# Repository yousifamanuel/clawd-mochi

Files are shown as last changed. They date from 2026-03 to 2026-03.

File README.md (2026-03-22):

<!-- LOGO -->
<p align="center">
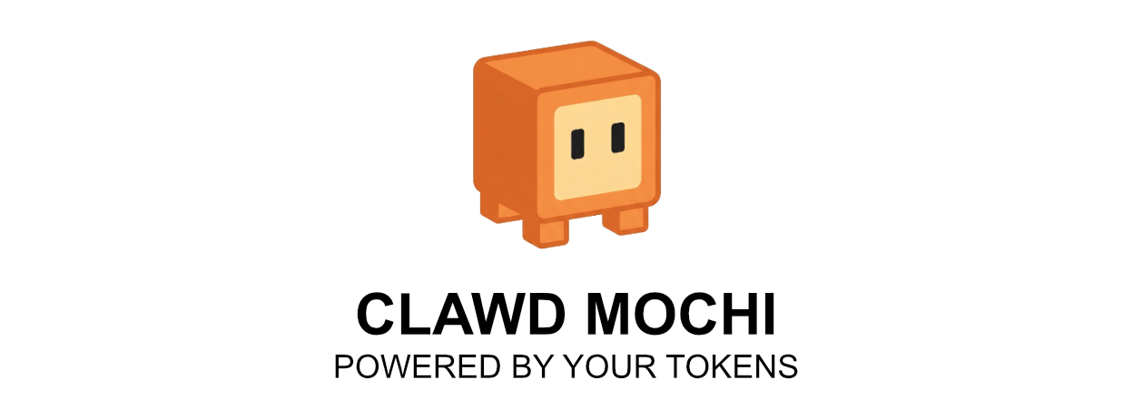
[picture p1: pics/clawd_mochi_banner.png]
Clawd Mochi Logo
  
</p>

# Clawd Mochi 🦀🤖

A physical desk companion inspired by **Clawd** — the pixel-crab mascot of Claude Code by Anthropic. An ESP32-C3 drives a 1.54" color TFT display and hosts a mobile web controller — no app, no internet, no cloud required.

**Cost: ~$6–8 · Build time: ~1 hour · Skill level: Beginner**

📦 3D printable case on MakerWorld: [https://makerworld.com/en/models/2559505-clawd-mochi-physical-claude-code-mascot#profileId-2820000](https://makerworld.com/en/models/2559505-clawd-mochi-physical-claude-code-mascot#profileId-2820000)

---

> ⚠️ This is an independent fan project. It is not affiliated with, sponsored by, or endorsed by Anthropic. "Claude" and "Clawd" are trademarks of Anthropic.

---

<p align="center">
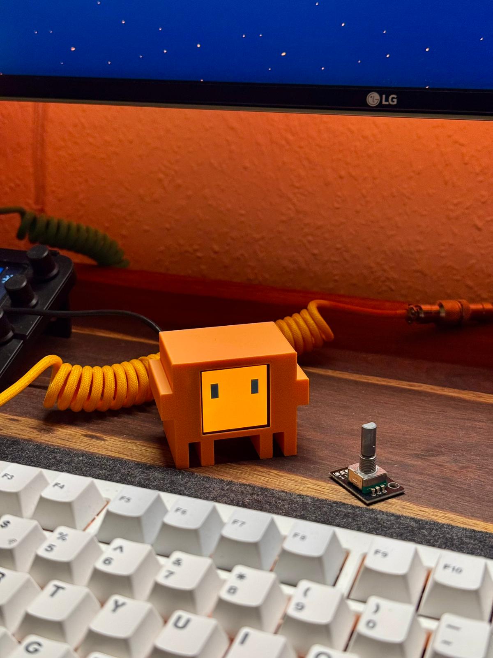
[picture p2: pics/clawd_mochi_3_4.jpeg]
Assembled Clawd Mochi on a desk
  
  &nbsp;
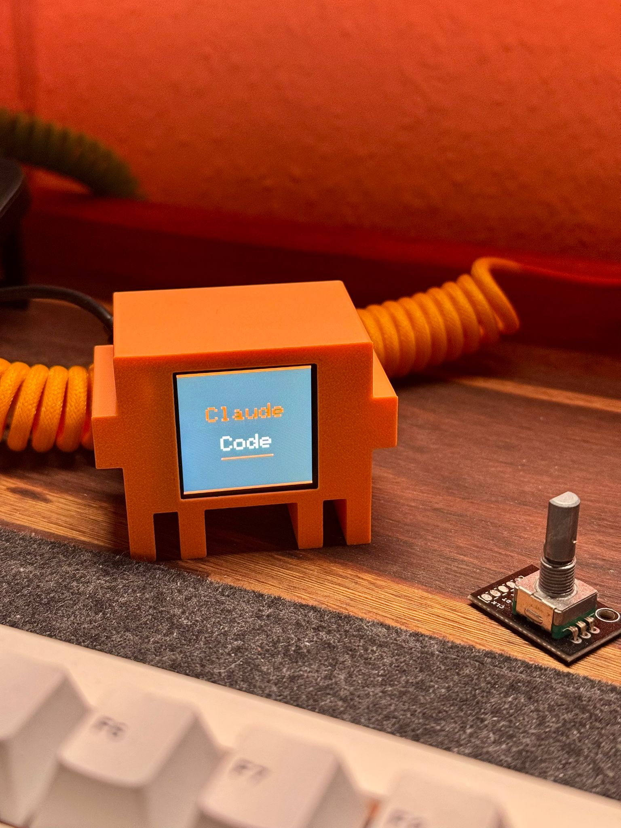
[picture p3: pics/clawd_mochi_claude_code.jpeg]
Claude Code view
  
</p>

## What it does

Clawd Mochi sits on your desk and shows animated expressions on a small color display. You control it from any phone or browser by connecting to its built-in WiFi hotspot:

- **Normal eyes** — pixel-art square eyes with wiggle and blink animations
- **Squish eyes** — `> <` happy squint with open/close animation
- **Claude Code** — displays "Claude Code" with an interactive terminal
- **Canvas** — draw anything on the display from your phone in real time

---

## Parts list

| Part | Spec | ~Price |
| --- | --- | --- |
| ESP32-C3 Super Mini | microcontroller with WiFi | ~$2.50 |
| ST7789 1.54" TFT | 240×240 SPI color display | ~$3.00 |
| 8 short wires | 8–10 cm Dupont / jumper wires | ~$0.50 |
| 2× M2×6mm screws | to mount display bezel | ~$0.10 |
| Double-sided tape | to secure components inside case | ~$0.10 |
| USB-C cable | for power | — |
| 3D printed case | PLA or PETG, ~30g | ~$0.50 |

**Total: ~$7–8**

---

## Wiring

> ⚠️ Connect VCC to **3.3V only** — never 5V. Use GPIO 8 and 10 for SPI (hardware SPI, fast). Do not use GPIO 6/7 for SPI.

| Display pin | ESP32-C3 GPIO  | Wire color (suggested) |
| --- | --- | --- |
| VCC | 3V3 | Red |
| GND | GND | Black |
| SDA | GPIO 10 (MOSI) | Orange |
| SCL | GPIO 8 (SCK) | Green |
| RES | GPIO 2 | Purple |
| DC | GPIO 1 | Blue |
| CS | GPIO 4 | White |
| BL | GPIO 3 | Yellow |

---

## Software setup

### Step 1 — Install Arduino IDE

Download [Arduino IDE 2.x](https://www.arduino.cc/en/software) and install it.

### Step 2 — Add ESP32 board support

1. Open Arduino IDE → **File → Preferences**
2. In "Additional boards manager URLs" paste:
   ```
   https://raw.githubusercontent.com/espressif/arduino-esp32/gh-pages/package_esp32_index.json
   ```
3. Go to **Tools → Board → Boards Manager**, search `esp32`, install **"esp32 by Espressif Systems"**

### Step 3 — Install libraries

Go to **Tools → Library Manager** and install both:

- `Adafruit GFX Library`
- `Adafruit ST7735 and ST7789 Library`

### Step 4 — Configure board settings

Go to **Tools** and set:

| Setting | Value |
| --- | --- |
| Board | ESP32C3 Dev Module |
| USB CDC On Boot | **Enabled** ← important |
| CPU Frequency | 160 MHz |
| Upload Speed | 921600 |

### Step 5 — Upload the sketch

1. Clone or download this repo
2. Open `clawd_mochi/clawd_mochi.ino` in Arduino IDE
3. Connect the ESP32 via USB-C
4. Select the correct port under **Tools → Port**
5. Click **Upload** (→ arrow button)
6. Wait for "Hard resetting via RTS pin..." — this means success

---

## How to use it

### Connect and open the controller

1. Power the ESP32 via USB-C (any USB charger or power bank)
2. Wait ~3 seconds for the boot animation to finish
3. On your phone or computer, go to **WiFi settings**
4. Connect to the network: **`ClaWD-Mochi`** · password: **`clawd1234`**
5. Open a browser and go to **`http://192.168.4.1`**

You should see the web controller:

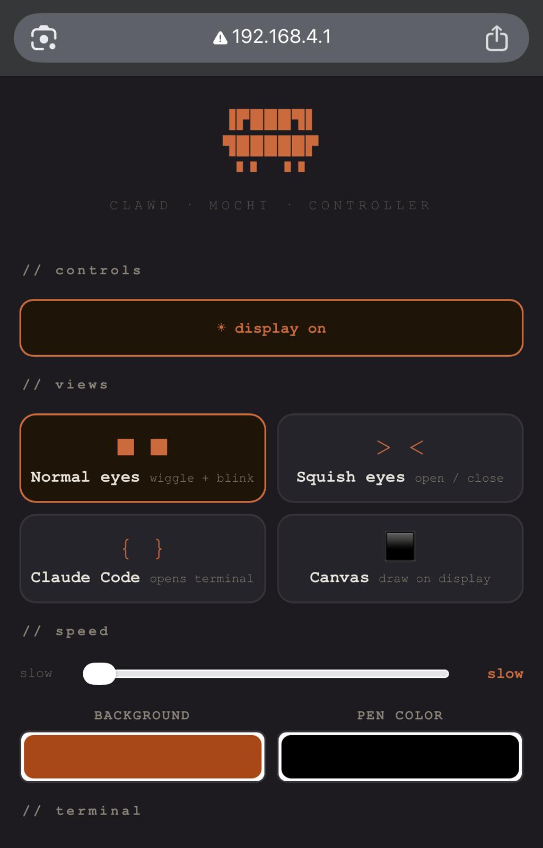
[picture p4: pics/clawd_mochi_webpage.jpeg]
Webpage view


### Controller features

| Button / control | What it does |
| --- | --- |
| Normal eyes | Plays wiggle + blink animation |
| Squish eyes | Plays open/close animation |
| Claude Code | Shows code display, opens terminal |
| Canvas | Enter drawing mode — draw on display from phone |
| Speed slider | Controls animation speed (slow / normal / fast) |
| Background color | Changes background color of all views |
| Pen color | Sets drawing color for canvas |
| Display on/off | Toggles the backlight |
| ✓ done (in canvas) | Exits canvas mode |

---

## 3D case

The case has two parts:

| File | Description |
| --- | --- |
| [`./models/clawd_mochi_body.stl`](./models/clawd_mochi_body.stl) | Main crab body with display window cutout |
| [`./models/clawd_mochi_back.stl`](./models/clawd_mochi_back.stl) | Back plate with USB-C access slot |

### Print settings

| Setting | Value |
| --- | --- |
| Material | PLA or PETG |
| Layer height | 0.15–0.20 mm |
| Infill | 15% gyroid |
| Supports | Yes — for display window overhang |
| Orientation  | Face-down, flat back on build plate |

Suggested colors: orange PLA for body, matte black for back plate.

You can also download the models from MakerWorld: [https://makerworld.com/en/models/2559505-clawd-mochi-physical-claude-code-mascot#profileId-2820000](https://makerworld.com/en/models/2559505-clawd-mochi-physical-claude-code-mascot#profileId-2820000)

---

## Assembly tips

1. Print both parts and test-fit the display before gluing anything
2. Thread the 8 wires through the back plate slot before soldering
3. Use double-sided tape to fix the ESP32 against the inside of the back plate
4. Secure the display with 2× M2×6mm screws through the bezel holes
5. Route the USB-C cable through the back plate slot and snap the back on

---

## Customisation

### Eye size and position

Edit these constants near the top of `clawd_mochi.ino`:

```cpp
#define EYE_W   30    // eye width in pixels
#define EYE_H   60    // eye height in pixels
#define EYE_GAP 120   // gap between eyes
#define EYE_OX  0     // horizontal offset
#define EYE_OY  40    // vertical offset upward
```

### Logo animation duration

```cpp
// In animLogoReveal() — how long logo holds after animation
delay(1500);       // milliseconds — change this number

// Speed of the reveal drawing stroke by stroke
delay(speedMs(8)); // lower = faster
```

---

## Contributing

Contributions are very welcome! Here are some ideas:

- **New animations** — add new expressions, transitions, or idle behaviors
- **New views** — weather display, clock, notification badges, pixel art scenes
- **Sound** — add a small buzzer for sound effects
- **Sensors** — connect a touch sensor or button for physical interaction
- **OTA updates** — add over-the-air firmware updates
- **MQTT / Home Assistant** — connect to smart home platforms

To contribute: fork the repo, make your changes, and open a pull request. Please keep the single-file structure (`clawd_mochi.ino`) so it stays easy for beginners to flash.

## License

This project is licensed under the MIT License — see the [LICENSE](LICENSE) file for details.

**Note:** 3D models and media assets are licensed under **CC BY-NC-SA 4.0**.

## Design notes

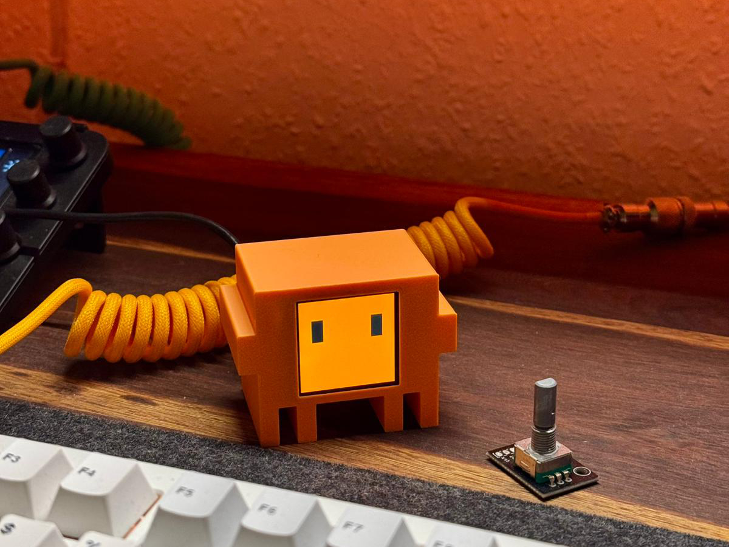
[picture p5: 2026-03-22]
pics/clawd_mochi_4_3.jpg

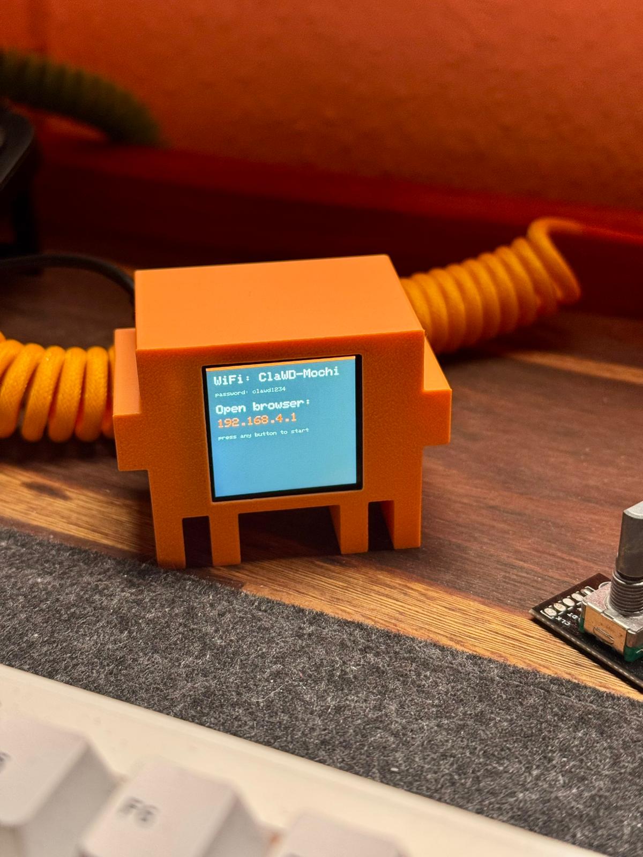
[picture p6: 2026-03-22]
pics/clawd_mochi_start.jpeg

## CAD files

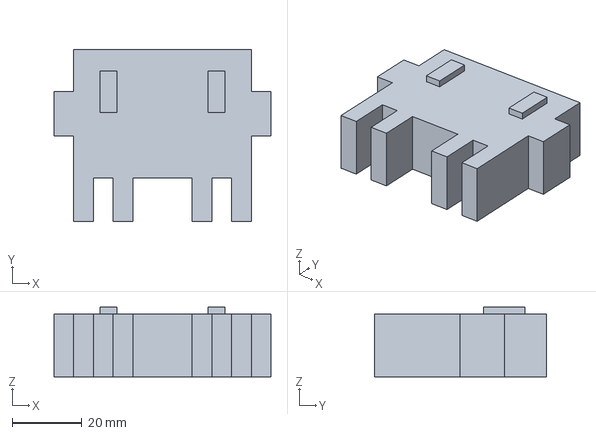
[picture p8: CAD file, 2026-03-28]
models/clawd_3d/Clawd_3D_AMS.3mf
62.4 x 49.5 x 20.0 mm

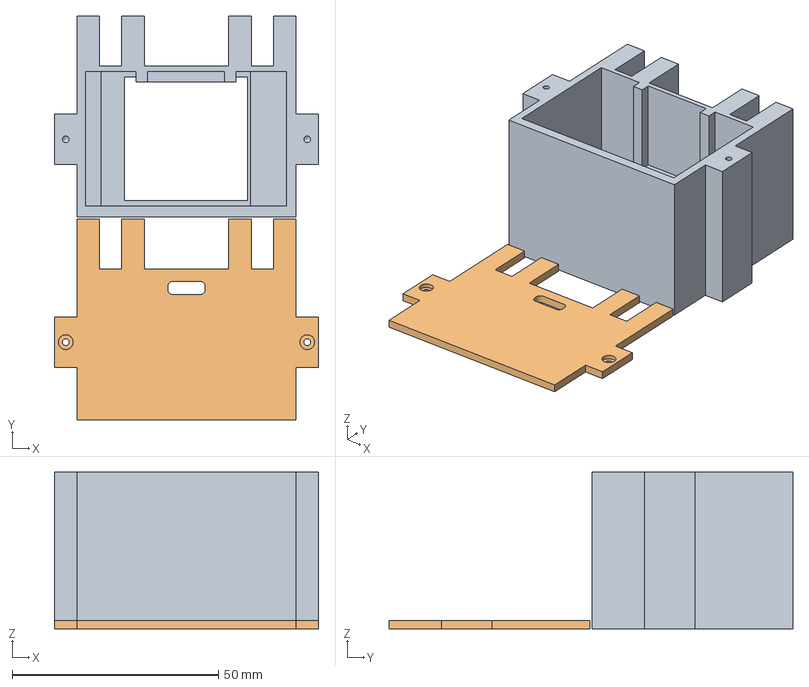
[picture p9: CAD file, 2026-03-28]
models/clawd_mochi/clawd_mochi_v1.3mf
63.9 x 97.7 x 38.0 mm
clawd_mochi.stl_2
clawd_mochi.stl_1

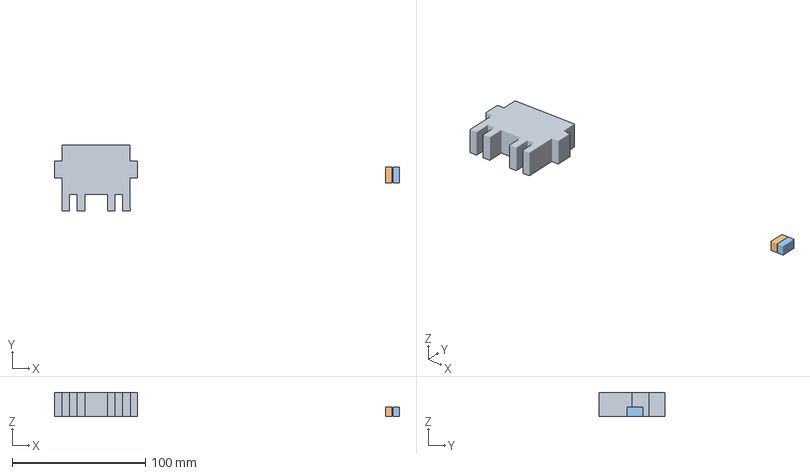
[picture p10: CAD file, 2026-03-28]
models/clawd_3d/Clawd_3D_no_AMS.3mf
258.4 x 49.5 x 18.0 mm
Clawd 3D.stl_1
Clawd 3D.stl_2
Clawd 3D.stl_3

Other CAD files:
models/clawd_3d/Clawd_3D_AMS.stl
models/clawd_3d/Clawd_3D_no_AMS.stl
models/clawd_mochi/clawd_mochi_v1.stl

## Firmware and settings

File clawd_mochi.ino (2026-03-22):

/*
 * ╔══════════════════════════════════════════════════════════════╗
 *   CLAWD MOCHI — ESP32-C3 Super Mini + ST7789 1.54" 240×240
 *
 *   Wiring:
 *     SDA → GPIO 10  (hardware SPI MOSI)
 *     SCL → GPIO 8   (hardware SPI SCK)
 *     RST → GPIO 2
 *     DC  → GPIO 1
 *     CS  → GPIO 4
 *     BL  → GPIO 3
 *     VCC → 3V3
 *     GND → GND
 *
 *   WiFi: "ClaWD-Mochi"  pw: clawd1234  → http://192.168.4.1
 * ╚══════════════════════════════════════════════════════════════╝
 */

#include <Adafruit_GFX.h>
#include <Adafruit_ST7789.h>
#include <SPI.h>
#include <math.h>
#include <WiFi.h>
#include <WebServer.h>

// ── Pins ──────────────────────────────────────────────────────
#define TFT_CS  4
#define TFT_DC  1
#define TFT_RST 2
#define TFT_BLK 3

Adafruit_ST7789 tft = Adafruit_ST7789(TFT_CS, TFT_DC, TFT_RST);

// ── WiFi ──────────────────────────────────────────────────────
const char* AP_SSID = "ClaWD-Mochi";
const char* AP_PASS = "clawd1234";
WebServer server(80);

// ── Display ───────────────────────────────────────────────────
#define DISP_W 240
#define DISP_H 240

// ── Eye constants (shared by both eye views) ──────────────────
#define EYE_W   30
#define EYE_H   60
#define EYE_GAP 120
#define EYE_OX  0     // horizontal offset
#define EYE_OY  40    // vertical offset upward (subtracted from centre)

// ── Colours ───────────────────────────────────────────────────
uint16_t C_ORANGE, C_DARKBG, C_MUTED, C_GREEN;
#define C_WHITE ST77XX_WHITE
#define C_BLACK ST77XX_BLACK

// ── State ─────────────────────────────────────────────────────
#define VIEW_EYES_NORMAL 0
#define VIEW_EYES_SQUISH 1
#define VIEW_CODE        2
#define VIEW_DRAW        3

uint8_t  currentView  = VIEW_EYES_NORMAL;
bool     busy         = false;
bool     backlightOn  = true;
uint8_t  animSpeed    = 1;   // 1=slow(default) 2=normal 3=fast

uint16_t animBgColor  = 0;   // background for eye/logo animations
uint16_t drawBgColor  = 0;   // background for canvas

// ── Terminal ──────────────────────────────────────────────────
#define TERM_COLS      15
#define TERM_ROWS       8
#define TERM_CHAR_W    12
#define TERM_CHAR_H    20
#define TERM_PAD_X      8
#define TERM_PAD_Y     18

bool    termMode    = false;
String  termLines[TERM_ROWS];
uint8_t termRow     = 0;
uint8_t termCol     = 0;

// ── Logo data ─────────────────────────────────────────────────
#define LOGO_CX 120
#define LOGO_CY 105

#define LOGO_TRI_COUNT 162
static const int16_t LOGO_TRIS[][6] PROGMEM = {
  {120,105,65,134,100,114},{120,105,100,114,101,113},{120,105,101,113,100,112},
  {120,105,100,112,99,112},{120,105,99,112,93,111},{120,105,93,111,73,111},
  {120,105,73,111,55,110},{120,105,55,110,38,109},{120,105,38,109,34,108},
  {120,105,34,108,30,103},{120,105,30,103,30,100},{120,105,30,100,34,98},
  {120,105,34,98,39,98},{120,105,39,98,50,99},{120,105,50,99,67,100},
  {120,105,67,100,80,101},{120,105,80,101,98,103},{120,105,98,103,101,103},
  {120,105,101,103,101,102},{120,105,101,102,100,101},{120,105,100,101,100,100},
  {120,105,100,100,82,88},{120,105,82,88,63,76},{120,105,63,76,53,69},
  {120,105,53,69,48,65},{120,105,48,65,45,61},{120,105,45,61,44,54},
  {120,105,44,54,49,49},{120,105,49,49,55,49},{120,105,55,49,57,49},
  {120,105,57,49,64,55},{120,105,64,55,78,66},{120,105,78,66,96,79},
  {120,105,96,79,99,81},{120,105,99,81,100,81},{120,105,100,81,100,80},
  {120,105,100,80,99,78},{120,105,99,78,89,60},{120,105,89,60,78,41},
  {120,105,78,41,73,34},{120,105,73,34,72,29},{120,105,72,29,72,28},
  {120,105,72,28,72,27},{120,105,72,27,71,26},{120,105,71,26,71,25},
  {120,105,71,25,71,24},{120,105,71,24,77,16},{120,105,77,16,80,15},
  {120,105,80,15,87,16},{120,105,87,16,91,19},{120,105,91,19,95,29},
  {120,105,95,29,103,46},{120,105,103,46,114,68},{120,105,114,68,118,75},
  {120,105,118,75,119,81},{120,105,119,81,120,83},{120,105,120,83,121,83},
  {120,105,121,83,121,82},{120,105,121,82,122,69},{120,105,122,69,124,54},
  {120,105,124,54,126,34},{120,105,126,34,126,28},{120,105,126,28,129,21},
  {120,105,129,21,135,18},{120,105,135,18,139,20},{120,105,139,20,143,25},
  {120,105,143,25,142,28},{120,105,142,28,140,42},{120,105,140,42,136,64},
  {120,105,136,64,133,78},{120,105,133,78,135,78},{120,105,135,78,136,76},
  {120,105,136,76,144,67},{120,105,144,67,156,51},{120,105,156,51,162,45},
  {120,105,162,45,168,38},{120,105,168,38,172,35},{120,105,172,35,180,35},
  {120,105,180,35,185,43},{120,105,185,43,183,52},{120,105,183,52,175,62},
  {120,105,175,62,168,71},{120,105,168,71,159,83},{120,105,159,83,153,94},
  {120,105,153,94,154,94},{120,105,154,94,155,94},{120,105,155,94,176,90},
  {120,105,176,90,188,88},{120,105,188,88,201,85},{120,105,201,85,208,88},
  {120,105,208,88,208,91},{120,105,208,91,206,97},{120,105,206,97,191,101},
  {120,105,191,101,174,104},{120,105,174,104,148,110},{120,105,148,110,148,111},
  {120,105,148,111,148,111},{120,105,148,111,160,112},{120,105,160,112,165,112},
  {120,105,165,112,177,112},{120,105,177,112,200,114},{120,105,200,114,205,118},
  {120,105,205,118,209,123},{120,105,209,123,208,126},{120,105,208,126,199,131},
  {120,105,199,131,187,128},{120,105,187,128,159,121},{120,105,159,121,149,119},
  {120,105,149,119,147,119},{120,105,147,119,147,120},{120,105,147,120,156,128},
  {120,105,156,128,170,141},{120,105,170,141,189,158},{120,105,189,158,190,163},
  {120,105,190,163,188,166},{120,105,188,166,185,166},{120,105,185,166,169,153},
  {120,105,169,153,162,148},{120,105,162,148,148,136},{120,105,148,136,147,136},
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
};

#define LOGO_SEG_COUNT 162
static const int16_t LOGO_SEGS[][4] PROGMEM = {
  {65,134,100,114},{100,114,101,113},{101,113,100,112},{100,112,99,112},
  {99,112,93,111},{93,111,73,111},{73,111,55,110},{55,110,38,109},
  {38,109,34,108},{34,108,30,103},{30,103,30,100},{30,100,34,98},
  {34,98,39,98},{39,98,50,99},{50,99,67,100},{67,100,80,101},
  {80,101,98,103},{98,103,101,103},{101,103,101,102},{101,102,100,101},
  {100,101,100,100},{100,100,82,88},{82,88,63,76},{63,76,53,69},
  {53,69,48,65},{48,65,45,61},{45,61,44,54},{44,54,49,49},
  {49,49,55,49},{55,49,57,49},{57,49,64,55},{64,55,78,66},
  {78,66,96,79},{96,79,99,81},{99,81,100,81},{100,81,100,80},
  {100,80,99,78},{99,78,89,60},{89,60,78,41},{78,41,73,34},
  {73,34,72,29},{72,29,72,28},{72,28,72,27},{72,27,71,26},
  {71,26,71,25},{71,25,71,24},{71,24,77,16},{77,16,80,15},
  {80,15,87,16},{87,16,91,19},{91,19,95,29},{95,29,103,46},
  {103,46,114,68},{114,68,118,75},{118,75,119,81},{119,81,120,83},
  {120,83,121,83},{121,83,121,82},{121,82,122,69},{122,69,124,54},
  {124,54,126,34},{126,34,126,28},{126,28,129,21},{129,21,135,18},
  {135,18,139,20},{139,20,143,25},{143,25,142,28},{142,28,140,42},
  {140,42,136,64},{136,64,133,78},{133,78,135,78},{135,78,136,76},
  {136,76,144,67},{144,67,156,51},{156,51,162,45},{162,45,168,38},
  {168,38,172,35},{172,35,180,35},{180,35,185,43},{185,43,183,52},
  {183,52,175,62},{175,62,168,71},{168,71,159,83},{159,83,153,94},
  {153,94,154,94},{154,94,155,94},{155,94,176,90},{176,90,188,88},
  {188,88,201,85},{201,85,208,88},{208,88,208,91},{208,91,206,97},
  {206,97,191,101},{191,101,174,104},{174,104,148,110},{148,110,148,111},
  {148,111,148,111},{148,111,160,112},{160,112,165,112},{165,112,177,112},
  {177,112,200,114},{200,114,205,118},{205,118,209,123},{209,123,208,126},
  {208,126,199,131},{199,131,187,128},{187,128,159,121},{159,121,149,119},
  {149,119,147,119},{147,119,147,120},{147,120,156,128},{156,128,170,141},
  {170,141,189,158},{189,158,190,163},{190,163,188,166},{188,166,185,166},
  {185,166,169,153},{169,153,162,148},{162,148,148,136},{148,136,147,136},
  {147,136,147,137},{147,137,150,142},{150,142,168,168},{168,168,169,176},
  {169,176,168,179},{168,179,163,180},{163,180,158,179},{158,179,148,165},
  {148,165,137,149},{137,149,129,134},{129,134,128,135},{128,135,123,189},
  {123,189,120,192},{120,192,115,194},{115,194,110,191},{110,191,108,185},
  {108,185,110,174},{110,174,113,160},{113,160,116,148},{116,148,118,134},
  {118,134,119,129},{119,129,119,129},{119,129,118,129},{118,129,107,144},
  {107,144,91,166},{91,166,78,180},{78,180,75,181},{75,181,70,178},
  {70,178,70,173},{70,173,73,169},{73,169,91,146},{91,146,102,132},
  {102,132,109,124},{109,124,109,123},{109,123,108,123},{108,123,61,153},
  {61,153,52,155},{52,155,49,151},{49,151,49,146},{49,146,51,144},
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
};

// ═════════════════════════════════════════════════════════════
//  HELPERS
// ═════════════════════════════════════════════════════════════

int speedMs(int ms) {
  if (animSpeed == 3) return ms / 2;
  if (animSpeed == 1) return ms * 2;
  return ms;
}

uint16_t hexToRgb565(String hex) {
  hex.replace("#", "");
  if (hex.length() != 6) return C_WHITE;
  long v = strtol(hex.c_str(), nullptr, 16);
  return tft.color565((v >> 16) & 0xFF, (v >> 8) & 0xFF, v & 0xFF);
}

void setBacklight(bool on) {
  backlightOn = on;
  digitalWrite(TFT_BLK, on ? HIGH : LOW);
}

void initColours() {
  // C_ORANGE = tft.color565(170, 72, 28);
  C_ORANGE = tft.color565(218, 17, 0);
  C_DARKBG = tft.color565(10,  12,  16);
  C_MUTED  = tft.color565(90,  88,  86);
  C_GREEN  = tft.color565(80, 220, 130);
  animBgColor = C_ORANGE;
  drawBgColor = C_ORANGE;
}

// ═════════════════════════════════════════════════════════════
//  LOGO
// ═════════════════════════════════════════════════════════════

void drawLogoFilled(uint16_t bg, uint16_t fg) {
  tft.fillScreen(bg);
  for (uint16_t i = 0; i < LOGO_TRI_COUNT; i++) {
    tft.fillTriangle(
      pgm_read_word(&LOGO_TRIS[i][0]), pgm_read_word(&LOGO_TRIS[i][1]),
      pgm_read_word(&LOGO_TRIS[i][2]), pgm_read_word(&LOGO_TRIS[i][3]),
      pgm_read_word(&LOGO_TRIS[i][4]), pgm_read_word(&LOGO_TRIS[i][5]),
      fg);
  }
  tft.setTextColor(fg); tft.setTextSize(2);
  tft.setCursor(LOGO_CX - 54, 210); tft.print("Anthropic");
  tft.setCursor(LOGO_CX - 53, 210); tft.print("Anthropic");
}

// ═════════════════════════════════════════════════════════════
//  VIEWS
// ═════════════════════════════════════════════════════════════

// Eye helpers — shared constants via #define EYE_*
inline int16_t eyeLX(int16_t ox) {
  return (DISP_W - (EYE_W * 2 + EYE_GAP)) / 2 + EYE_OX + ox;
}
inline int16_t eyeRX(int16_t ox) { return eyeLX(ox) + EYE_W + EYE_GAP; }
inline int16_t eyeY()            { return (DISP_H - EYE_H) / 2 - EYE_OY; }
inline int16_t eyeCY()           { return eyeY() + EYE_H / 2; }

void drawNormalEyes(int16_t ox = 0, bool blink = false) {
  tft.fillScreen(animBgColor);
  const int16_t lx = eyeLX(ox), rx = eyeRX(ox), ey = eyeY();
  if (!blink) {
    tft.fillRect(lx, ey, EYE_W, EYE_H, C_BLACK);
    tft.fillRect(rx, ey, EYE_W, EYE_H, C_BLACK);
  } else {
    tft.fillRect(lx, ey + EYE_H / 2 - 3, EYE_W, 6, C_BLACK);
    tft.fillRect(rx, ey + EYE_H / 2 - 3, EYE_W, 6, C_BLACK);
  }
}

void drawChevron(int16_t cx, int16_t cy, int16_t arm, int16_t reach,
                 uint8_t thk, bool rightFacing, uint16_t col) {
  for (int8_t t = -(int8_t)thk; t <= (int8_t)thk; t++) {
    if (rightFacing) {
      tft.drawLine(cx - reach/2, cy - arm + t, cx + reach/2, cy + t,      col);
      tft.drawLine(cx + reach/2, cy + t,       cx - reach/2, cy + arm + t, col);
    } else {
      tft.drawLine(cx + reach/2, cy - arm + t, cx - reach/2, cy + t,      col);
      tft.drawLine(cx - reach/2, cy + t,       cx + reach/2, cy + arm + t, col);
    }
  }
}

void drawSquishEyes(bool closed = false) {
  tft.fillScreen(animBgColor);
  const int16_t lx = eyeLX(0), rx = eyeRX(0), cy = eyeCY();
  const int16_t arm   = EYE_H / 2;
  const int16_t reach = EYE_W / 2;
  const int16_t lcx   = lx + EYE_W / 2;
  const int16_t rcx   = rx + EYE_W / 2;
  if (!closed) {
    drawChevron(lcx, cy, arm, reach, 10, true,  C_BLACK);
    drawChevron(rcx, cy, arm, reach, 10, false, C_BLACK);
  } else {
    tft.fillRect(lx, cy - 5, EYE_W, 10, C_BLACK);
    tft.fillRect(rx, cy - 5, EYE_W, 10, C_BLACK);
  }
}

void drawCodeView() {
  termMode = false;
  tft.fillScreen(C_DARKBG);
  tft.fillRect(0, 0,          DISP_W, 4, C_ORANGE);
  tft.fillRect(0, DISP_H - 4, DISP_W, 4, C_ORANGE);
  tft.setTextColor(C_ORANGE); tft.setTextSize(4);
  tft.setCursor((DISP_W - 144) / 2, DISP_H / 2 - 52); tft.print("Claude");
  tft.setTextColor(C_WHITE);  tft.setTextSize(4);
  tft.setCursor((DISP_W - 96) / 2,  DISP_H / 2 + 8);  tft.print("Code");
  tft.fillRect((DISP_W - 96) / 2, DISP_H / 2 + 52, 96, 3, C_ORANGE);
}

// ═════════════════════════════════════════════════════════════
//  TERMINAL
// ═════════════════════════════════════════════════════════════

void termClear() {
  for (uint8_t i = 0; i < TERM_ROWS; i++) termLines[i] = "";
  termRow = 0; termCol = 0;
}

void termDrawHeader() {
  tft.fillRect(0, 0, DISP_W, TERM_PAD_Y + 1, C_DARKBG);
  tft.setTextColor(C_ORANGE); tft.setTextSize(1);
  tft.setCursor(TERM_PAD_X, 4); tft.print("clawd@mochi terminal");
  tft.drawFastHLine(0, TERM_PAD_Y, DISP_W, C_ORANGE);
}

// Prefix "clawd:~$ " in green, drawn only when the row has content
void termDrawPrefix(int16_t yy) {
  tft.setTextColor(C_GREEN); tft.setTextSize(1);
  tft.setCursor(TERM_PAD_X, yy + 6);
  tft.print("clawd:~$ ");
}

#define PREFIX_PX 54   // 9 chars × 6px = 54px at textSize 1

void termDrawLine(uint8_t r) {
  const int16_t yy = TERM_PAD_Y + 4 + r * TERM_CHAR_H;
  tft.fillRect(0, yy, DISP_W, TERM_CHAR_H, C_DARKBG);
  // show prefix only on the currently active (cursor) line
  if (r == termRow) termDrawPrefix(yy);
  tft.setTextColor(C_WHITE); tft.setTextSize(2);
  tft.setCursor(TERM_PAD_X + PREFIX_PX, yy + 1);
  tft.print(termLines[r]);
  if (r == termRow) {
    const int16_t cx = TERM_PAD_X + PREFIX_PX + termCol * TERM_CHAR_W;
    tft.fillRect(cx, yy + 1, TERM_CHAR_W - 2, TERM_CHAR_H - 2, C_GREEN);
  }
}

void termDrawLastChar() {
  if (termCol == 0) return;
  const int16_t yy    = TERM_PAD_Y + 4 + termRow * TERM_CHAR_H;
  const int16_t baseX = TERM_PAD_X + PREFIX_PX;
  const uint8_t prev  = termCol - 1;
  // erase prev cell (had cursor block)
  tft.fillRect(baseX + prev * TERM_CHAR_W, yy + 1, TERM_CHAR_W, TERM_CHAR_H - 1, C_DARKBG);
  tft.setTextColor(C_WHITE); tft.setTextSize(2);
  tft.setCursor(baseX + prev * TERM_CHAR_W, yy + 1);
  tft.print(termLines[termRow][prev]);
  // new cursor
  tft.fillRect(baseX + termCol * TERM_CHAR_W, yy + 1, TERM_CHAR_W - 2, TERM_CHAR_H - 2, C_GREEN);
}

void termDrawBackspace() {
  const int16_t yy    = TERM_PAD_Y + 4 + termRow * TERM_CHAR_H;
  const int16_t baseX = TERM_PAD_X + PREFIX_PX;
  // erase deleted char + old cursor
  tft.fillRect(baseX + termCol * TERM_CHAR_W, yy + 1, TERM_CHAR_W * 2, TERM_CHAR_H - 1, C_DARKBG);
  // new cursor
  tft.fillRect(baseX + termCol * TERM_CHAR_W, yy + 1, TERM_CHAR_W - 2, TERM_CHAR_H - 2, C_GREEN);
  // if line now empty, erase the prefix too
  if (termLines[termRow].length() == 0) {
    tft.fillRect(0, yy, TERM_PAD_X + PREFIX_PX, TERM_CHAR_H, C_DARKBG);
  }
}

void termFullRedraw() {
  tft.fillScreen(C_DARKBG);
  termDrawHeader();
  for (uint8_t r = 0; r < TERM_ROWS; r++) termDrawLine(r);
}

void termScroll() {
  for (uint8_t i = 0; i < TERM_ROWS - 1; i++) termLines[i] = termLines[i + 1];
  termLines[TERM_ROWS - 1] = "";
  termRow = TERM_ROWS - 1;
  termFullRedraw();
}

void termAddChar(char c) {
  if (c == '\n' || c == '\r') {
    const int16_t yy = TERM_PAD_Y + 4 + termRow * TERM_CHAR_H;
    // erase cursor on current row
    tft.fillRect(TERM_PAD_X + PREFIX_PX + termCol * TERM_CHAR_W,
                 yy + 1, TERM_CHAR_W, TERM_CHAR_H - 1, C_DARKBG);
    termRow++; termCol = 0;
    if (termRow >= TERM_ROWS) { termScroll(); return; }
    termDrawLine(termRow);  // draws prefix on new line
  } else if (c == '\b' || c == 127) {
    if (termCol > 0) {
      termCol--;
      termLines[termRow].remove(termLines[termRow].length() - 1);
      termDrawBackspace();
    }
  } else if (c >= 32 && c < 127) {
    if (termCol >= TERM_COLS) {
      termRow++; termCol = 0;
      if (termRow >= TERM_ROWS) { termScroll(); return; }
    }
    // draw prefix on first char of this line
    if (termCol == 0) termDrawPrefix(TERM_PAD_Y + 4 + termRow * TERM_CHAR_H);
    termLines[termRow] += c;
    termCol++;
    termDrawLastChar();
  }
}

// ═════════════════════════════════════════════════════════════
//  ANIMATIONS
// ═════════════════════════════════════════════════════════════

void animNormalEyes() {
  busy = true;
  const int16_t offs[] = {-16, 16, -16, 16, 0};
  for (uint8_t i = 0; i < 5; i++) { drawNormalEyes(offs[i]); delay(speedMs(80)); }
  drawNormalEyes(0, true);  delay(speedMs(100));
  drawNormalEyes(0, false); delay(speedMs(70));
  drawNormalEyes(0, true);  delay(speedMs(70));
  drawNormalEyes(0, false);
  busy = false;
}

void animSquishEyes() {
  busy = true;
  for (uint8_t i = 0; i < 3; i++) {
    drawSquishEyes(false); delay(speedMs(160));
    drawSquishEyes(true);  delay(speedMs(100));
  }
  drawSquishEyes(false);
  busy = false;
}

void animLogoReveal() {
  busy = true;
  tft.fillScreen(animBgColor);
  for (uint16_t i = 0; i < LOGO_SEG_COUNT; i++) {
    int16_t x1 = pgm_read_word(&LOGO_SEGS[i][0]);
    int16_t y1 = pgm_read_word(&LOGO_SEGS[i][1]);
    int16_t x2 = pgm_read_word(&LOGO_SEGS[i][2]);
    int16_t y2 = pgm_read_word(&LOGO_SEGS[i][3]);
    tft.drawLine(x1, y1, x2, y2, C_WHITE);
    tft.drawLine(x1 + 1, y1, x2 + 1, y2, C_WHITE);
    if (i % 4 == 0) { server.handleClient(); delay(speedMs(8)); }
  }
  drawLogoFilled(animBgColor, C_WHITE);
  delay(1500);
  busy = false;
}

// ═════════════════════════════════════════════════════════════
//  WEB PAGE
// ═════════════════════════════════════════════════════════════
const char INDEX_HTML[] PROGMEM = R"rawhtml(
<!DOCTYPE html>
<html lang="en">
<head>
<meta charset="UTF-8">
<meta name="viewport" content="width=device-width,initial-scale=1,user-scalable=no">
<title>Clawd Mochi</title>
<style>
*{box-sizing:border-box;margin:0;padding:0;-webkit-tap-highlight-color:transparent}
body{background:#1c1c20;font-family:'Courier New',monospace;color:#e8e4dc;
  display:flex;flex-direction:column;align-items:center;
  padding:20px 14px 52px;gap:14px;min-height:100vh}

.hdr{text-align:center;padding:2px 0 4px}
.mascot{font-size:15px;color:#c96a3e;line-height:1.3;font-weight:bold;
  font-family:'Courier New',monospace;display:block;letter-spacing:1px}
.sitename{font-size:10px;color:#5a5048;margin-top:8px;letter-spacing:3px}

.sec{width:100%;max-width:390px;font-size:10px;color:#8a8278;
  letter-spacing:2px;font-weight:bold;padding:0 2px}

/* Busy bar */
.busy{width:100%;max-width:390px;height:2px;background:#2e2a28;
  border-radius:1px;overflow:hidden;opacity:0;transition:opacity .2s}
.busy.show{opacity:1}
.busy-i{height:100%;width:30%;background:#c96a3e;border-radius:1px;
  animation:sl 1s linear infinite}
@keyframes sl{0%{margin-left:-30%}100%{margin-left:100%}}

/* Controls */
.ctrl{display:flex;gap:8px;width:100%;max-width:390px}
.cbtn{flex:1;background:#252428;border:1.5px solid #38343a;border-radius:10px;
  color:#b8b4ac;font-family:'Courier New',monospace;font-size:11px;font-weight:bold;
  padding:12px 4px;cursor:pointer;text-align:center;transition:all .12s}
.cbtn:active:not(:disabled){transform:scale(.94)}
.cbtn:disabled{opacity:.3;cursor:default}
.cbtn.on{border-color:#c96a3e;color:#c96a3e;background:#201408}
.cbtn.dim{border-color:#2e2a28;color:#4a4540}

/* View grid */
.vgrid{display:grid;grid-template-columns:1fr 1fr;gap:8px;width:100%;max-width:390px}
.vbtn{background:#252428;border:1.5px solid #38343a;border-radius:12px;
  color:#d8d4cc;font-family:'Courier New',monospace;
  padding:14px 6px 10px;cursor:pointer;text-align:center;
  transition:all .12s;user-select:none}
.vbtn:active:not(:disabled){transform:scale(.94)}
.vbtn:disabled{opacity:.3;cursor:default}
.vbtn .ic{font-size:20px;display:block;margin-bottom:4px;line-height:1;color:#c96a3e}
.vbtn .nm{font-size:12px;font-weight:bold;color:#e8e4dc}
.vbtn .ht{font-size:9px;color:#8a8278;margin-top:3px}
.vbtn.active{border-color:#c96a3e;background:#201408}
.vbtn[data-v="1"].active{border-color:#c96a3e;background:#201408}
.vbtn[data-v="2"].active{border-color:#4a8acd;background:#0c1628}
.vbtn[data-v="3"].active{border-color:#38343a;background:#201c18}

/* Speed slider */
.speed-row{width:100%;max-width:390px;display:flex;align-items:center;gap:10px}
.sl{font-size:10px;color:#6a6058;white-space:nowrap;min-width:36px}
input[type=range]{flex:1;accent-color:#c96a3e;cursor:pointer;height:20px}
.sv{font-size:11px;color:#c96a3e;min-width:44px;text-align:right;font-weight:bold}

/* Terminal */
.twrap{width:100%;max-width:390px;display:none;flex-direction:column;gap:8px}
.twrap.open{display:flex}
.thdr{display:flex;justify-content:space-between;align-items:center}
.tttl{font-size:11px;color:#28b878;letter-spacing:1px;font-weight:bold}
.tx{background:#0c1e12;border:2px solid #1a4828;border-radius:9px;
  color:#28b878;font-family:'Courier New',monospace;font-size:13px;
  font-weight:bold;padding:10px 18px;cursor:pointer}
.tx:active{background:#081410}
.trow{display:flex;gap:6px}
.tin{flex:1;background:#0c1018;border:1.5px solid #1a2820;border-radius:9px;
  color:#40d880;font-family:'Courier New',monospace;font-size:15px;
  padding:11px;outline:none}
.tin::placeholder{color:#2a3828}
.tgo{background:#1a9060;border:none;border-radius:9px;color:#fff;
  font-family:'Courier New',monospace;font-size:22px;font-weight:bold;
  padding:11px 16px;cursor:pointer;min-width:52px}
.tgo:active{background:#0f6040}
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
void loop() { server.handleClient(); }

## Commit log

2026-03-22 🦀 init: first release
    [clawd_mochi.3mf, clawd_mochi.stl, clawd_mochi_back.3mf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]
2026-03-28 📦 chore: reorganize 3D model files into dedicated folders
    [Clawd_3D_AMS.3mf, Clawd_3D_AMS.stl, Clawd_3D_no_AMS.3mf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]
